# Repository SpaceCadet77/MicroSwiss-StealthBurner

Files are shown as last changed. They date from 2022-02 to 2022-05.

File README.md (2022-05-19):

# MicroSwiss-StealthBurner
Voron StealthBurner modified to work with a MicroSwiss Direct drive extruder system or Creality, Ender, CR-10 Printer.    

Thingiverse: https://www.thingiverse.com/thing:5232759
Printables: https://www.printables.com/model/157664-micro-swiss-stealthburner-beta

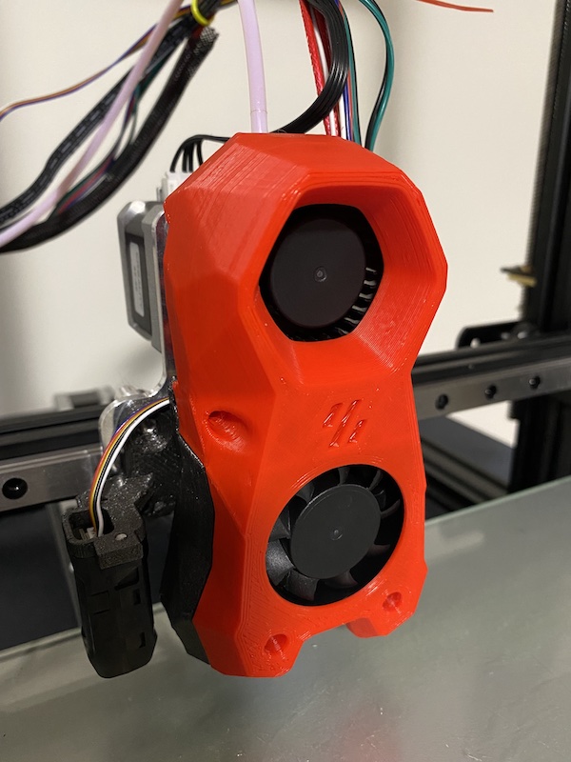
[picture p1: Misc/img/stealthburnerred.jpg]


## May 5, 2022:
- Fixed height adjustment
- Universal Mounting plate
- Use bottom insert for better adjustment
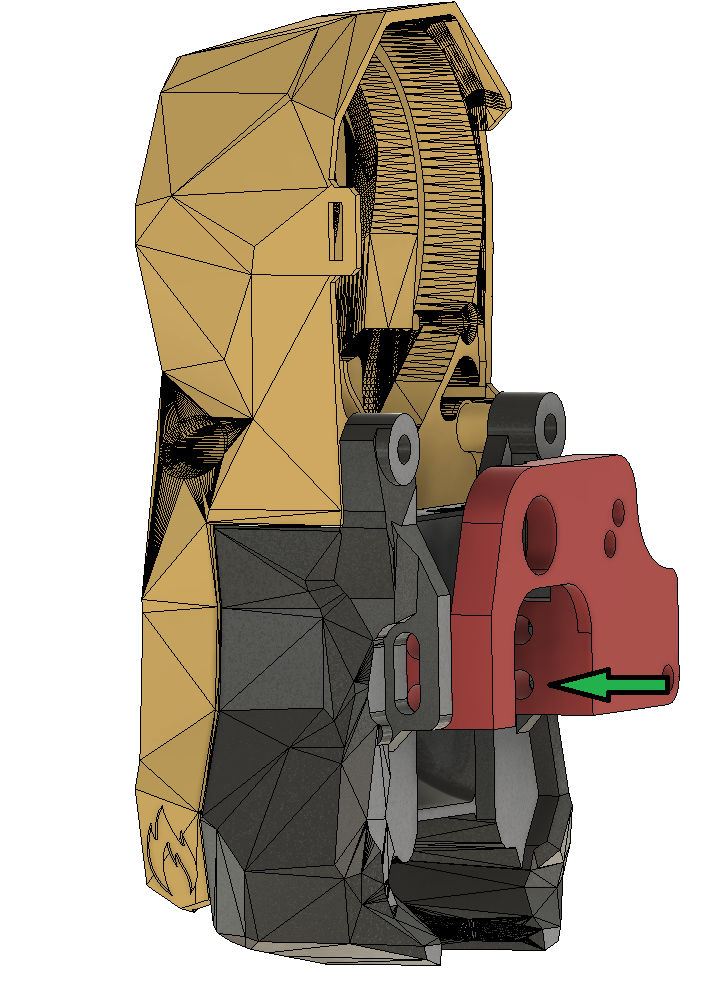
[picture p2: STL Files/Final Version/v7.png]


## Apr 18, 2022: 
- Was asked for an Ender3V2 Mounting plate. I took the dimensions from an existing STP file on Thingiverse (https://www.thingiverse.com/thing:4573240)
- If anyone is willing to test print/comment on changes
- Added through holes for wheel bolts
- Changed mouting bolt location
- File is Ender3V2PlateMountv1
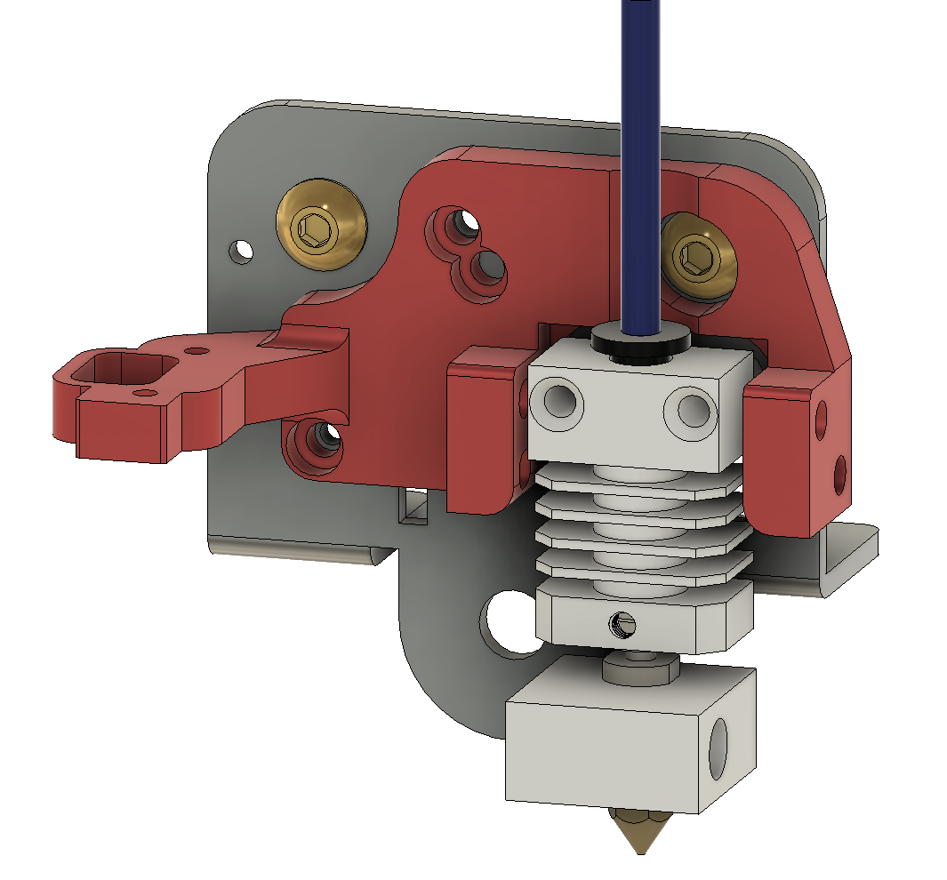
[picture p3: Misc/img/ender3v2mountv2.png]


## Mar 19, 2022: 
- Modified Fan_Sytem_V6, I have removed the bottom sections for Neopixels
- This is basically to clean it up if you arent using them, and to provide more room to view/work.
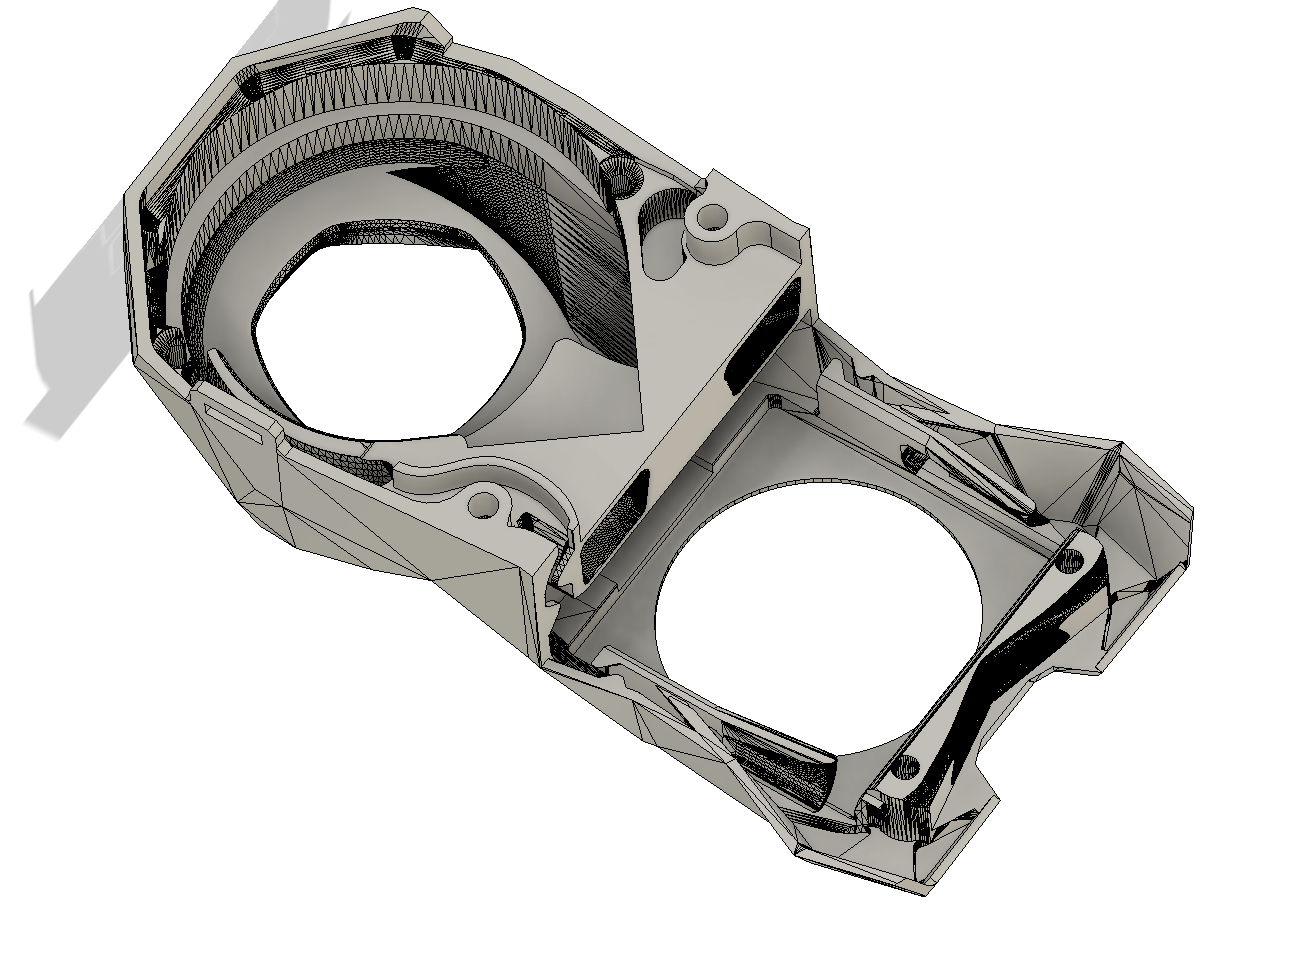
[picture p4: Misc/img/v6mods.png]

- Added some cable managment.

- Modified Duct_System_V6, by removing the inner splitter.
- I suppose I get the original intent, but at this scale creates backpressure.  
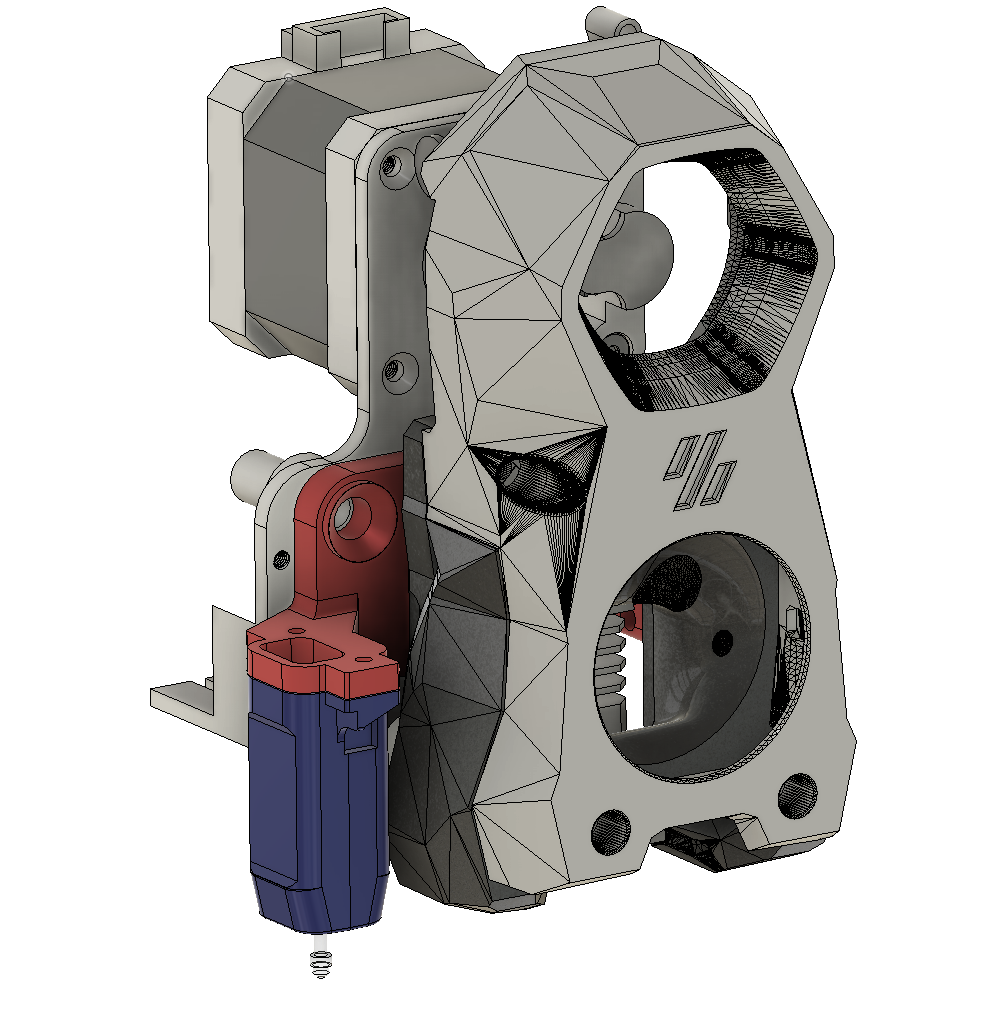
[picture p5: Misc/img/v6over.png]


- I have not printed these yet**
- 
## Feb 12, 2022: 
- Added vertical adjustment to Duct_System_V5.stl
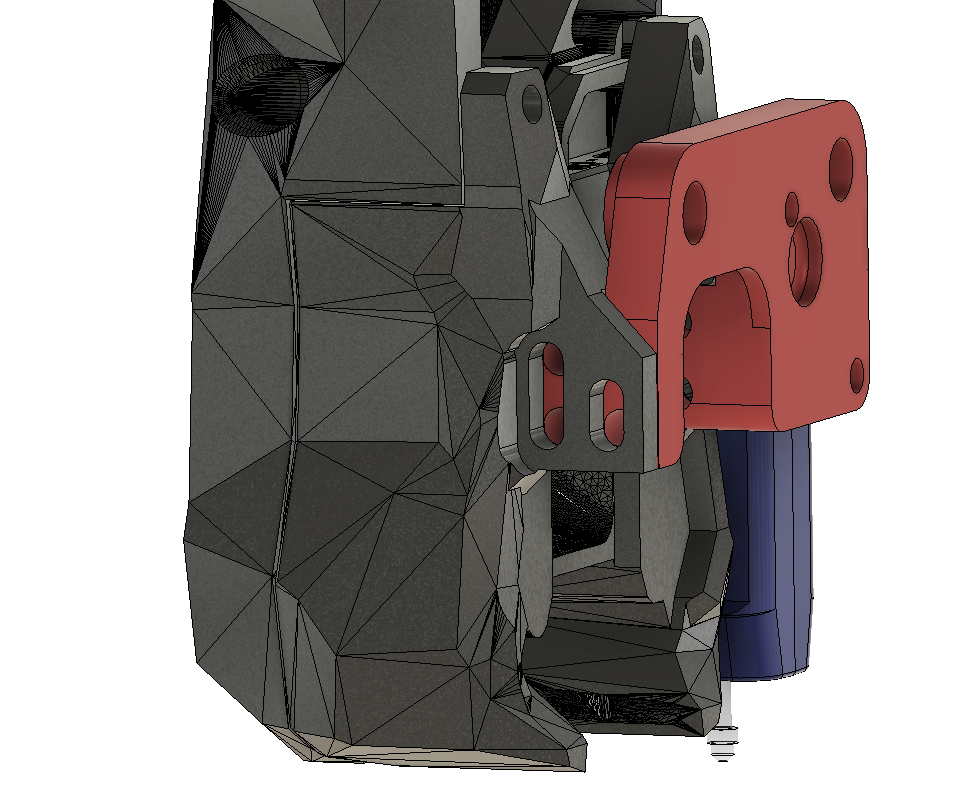
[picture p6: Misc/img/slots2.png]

- Added vertical adjustment holes to back_plate_mount_CRTouch_V5.stl.
- Will edit threaded instert depths, as there isnt much room for squishout 

## Feb 11, 2022: 
- Added Cable tie on right side (Fan_System_V5.stl)
- Added solid extrusion to remove the front logo through hole. This is used in the case you do not want to add an LED logo. (Fan_System_V5.stl)
- Added Extrusion Knob V1. Center Bore is 5.2 mm, OD is 47.0 mm, thickness is 5.0 mm
- Removed sectioned required for clockwork 2, unneeded for this mod. (Fan_System_V5.stl)

Files:
- back_plate_mount_CRTouch_V4.stl
- back_plate_mount_No_Probe_V4.stl
- Duct_System_V4.stl
- Fan_System_V5.stl

## Feb 4, 2022:
- This does not require any hardware modifications.
- This is still a beta design, as reverse engineering an STL is difficult.

Files:
- back_plate_mount_CRTouch_V4.stl
- back_plate_mount_No_Probe_V4.stl
- Duct_System_V4.stl
- Fan_System_V4.stl

Stay tuned for an additional modifications:

Extruder wheel (In Progress)
Extruder wheel side cutout of Fan System body (In Progress)
Wire management

Notes:
- The back plate and Duct System are currently attached with 4 M3*10 mm cap screws. This was to reduce a moment. After installation, it seams one screw on each side is sufficient.
- The Duct System and Back Mounting Plate are designed to use M3 threaded insert's (Red).
- There are 4 mounting locations (Green), I tapped the two wheel holes on the back mounting plate with a 1/4-20 tap. After mounting realized that's maybe a bit overkill, we'll see.

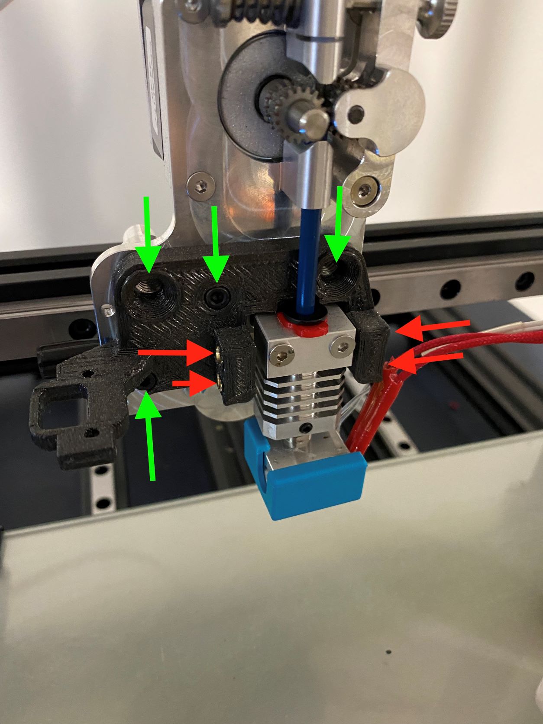
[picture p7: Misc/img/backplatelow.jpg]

     
- After calibrating my CR-Touch, my offset was -1.94, But please don't trust this value, as yours will be different. Probe to Nozzle was around 44, and 7 mm. This is mounted with 2 M3 screws, I did not use threaded inserts for this, but simply tapped the PETG.
- The Duct system currently requires supports for the top two "ears". I can probably redesign this with a 45 degree slope.

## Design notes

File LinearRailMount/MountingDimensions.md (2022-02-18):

To mount the Cr10/ender style microswiss backplate to the MGN12 linear block, I had to drill 3* 4mm holes.
This allowed a little bit of play for the M3*12mm screws. 
Using an ender5 style backplate would of been easier, but this has been working fine. 
Dimensions are shown below.

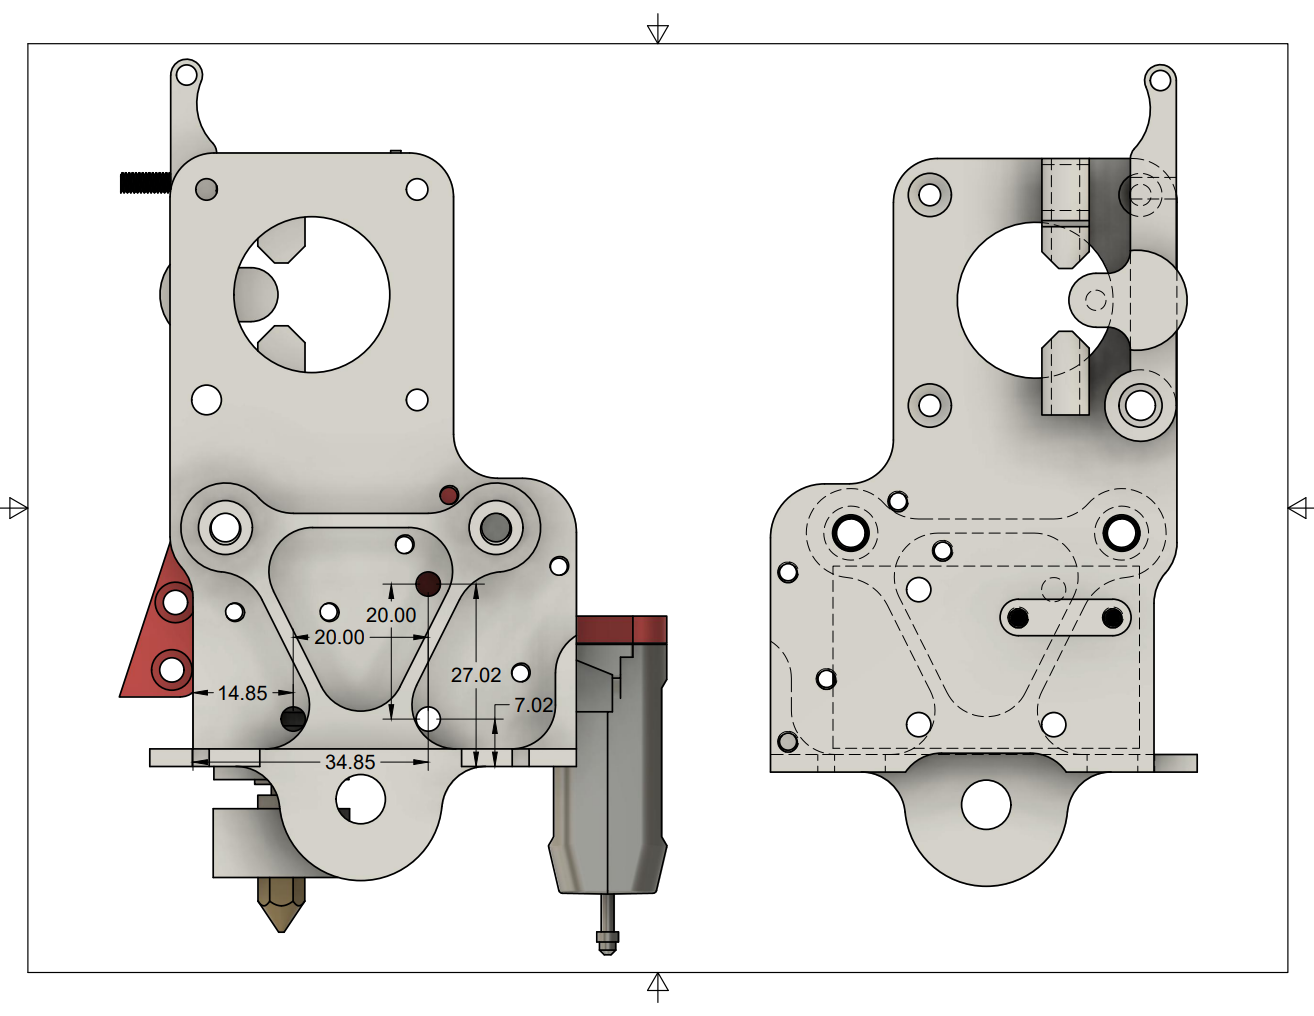
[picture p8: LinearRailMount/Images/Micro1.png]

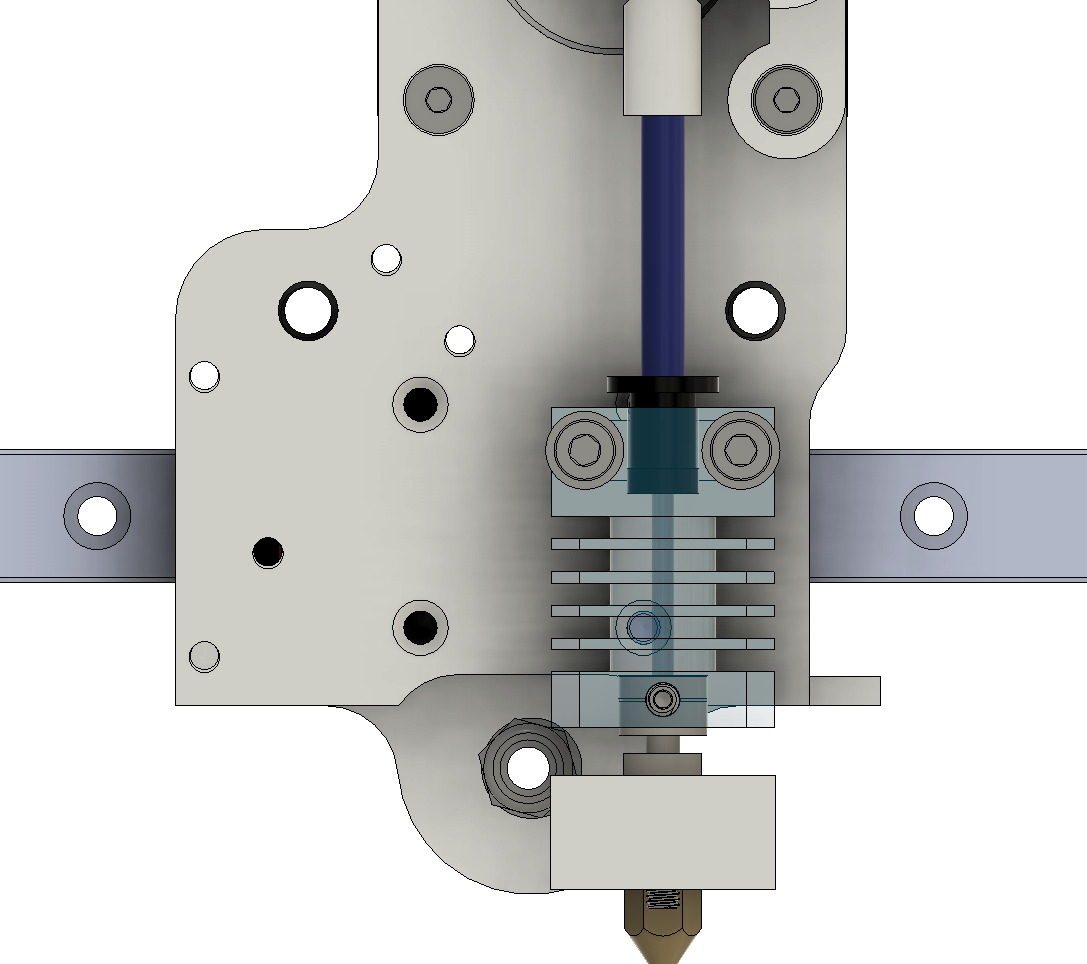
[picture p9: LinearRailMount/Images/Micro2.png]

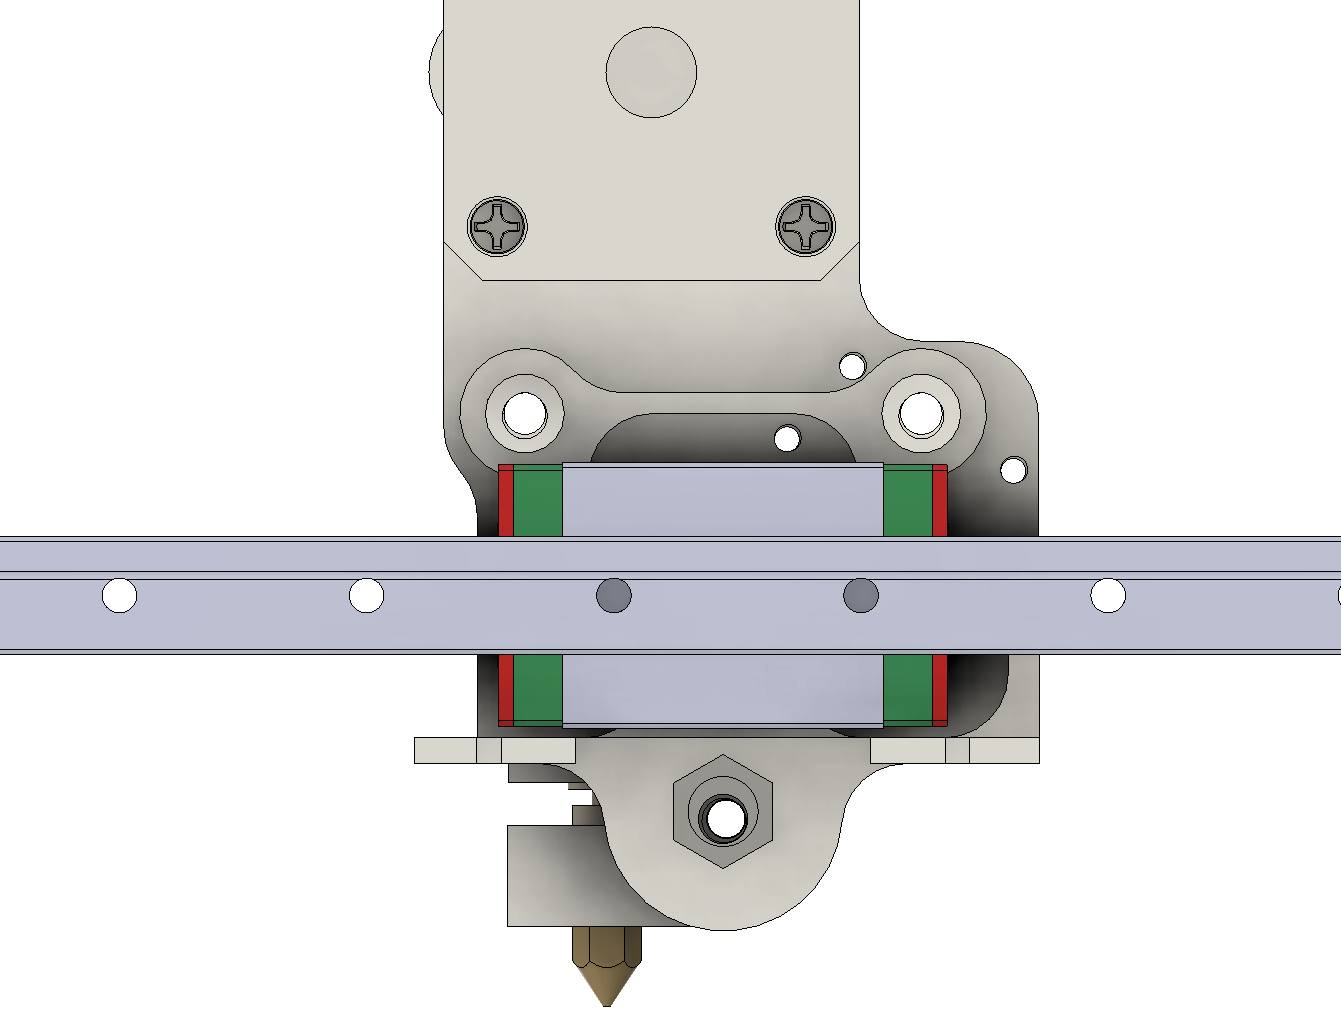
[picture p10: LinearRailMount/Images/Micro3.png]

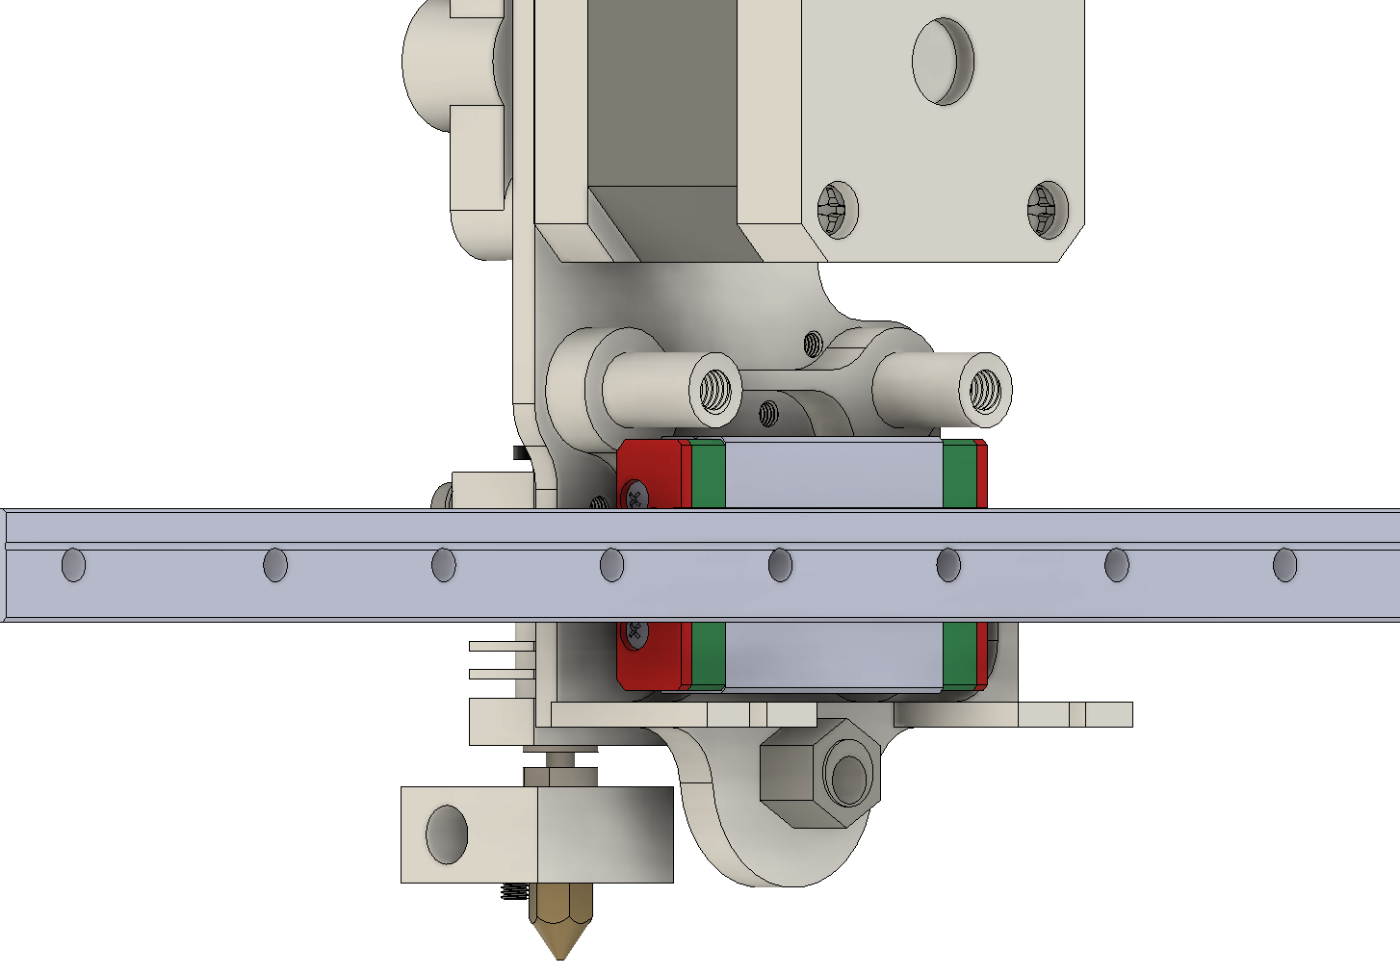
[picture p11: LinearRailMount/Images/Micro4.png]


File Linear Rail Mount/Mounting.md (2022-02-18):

To mount the original CR-10/Ender Style Microswiss plate to a MGN12 block, I drilled 3 holes in the microswiss Backplate. 
Dimensions are shown below. 




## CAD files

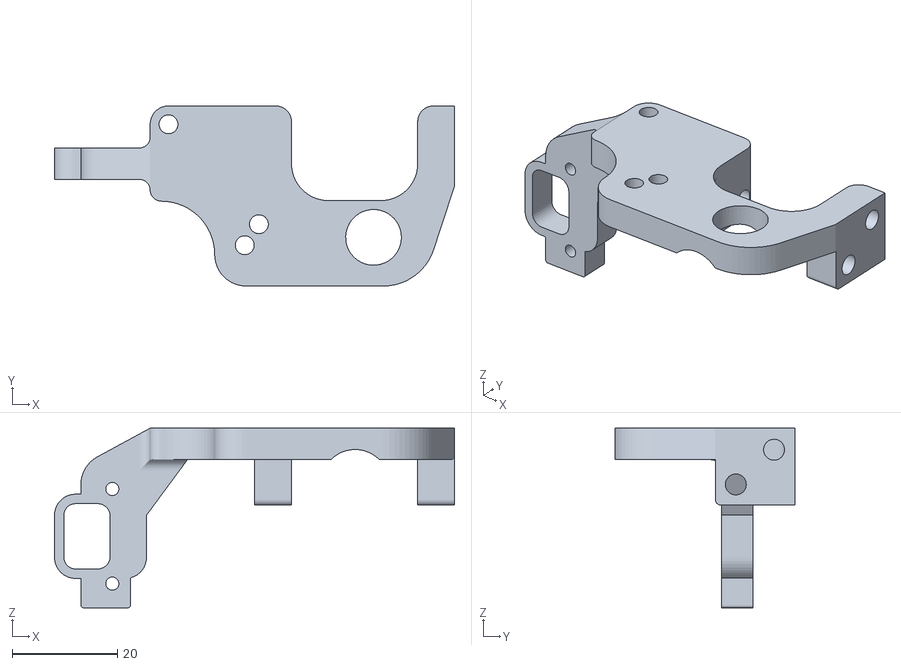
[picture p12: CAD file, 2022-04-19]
STL Files/Ender3V2PlateMountv1.stl
76.1 x 34.3 x 34.2

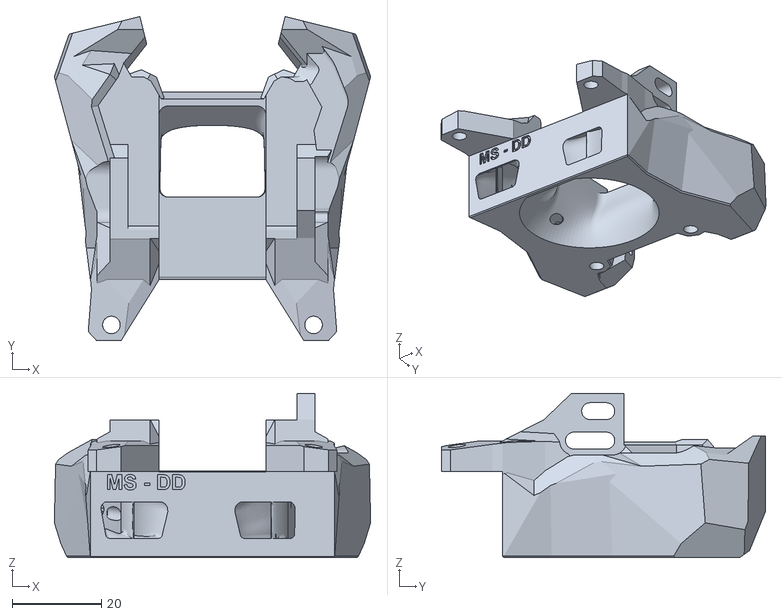
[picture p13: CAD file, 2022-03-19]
STL Files/Duct_System_V6.stl
71.1 x 72.8 x 36.9

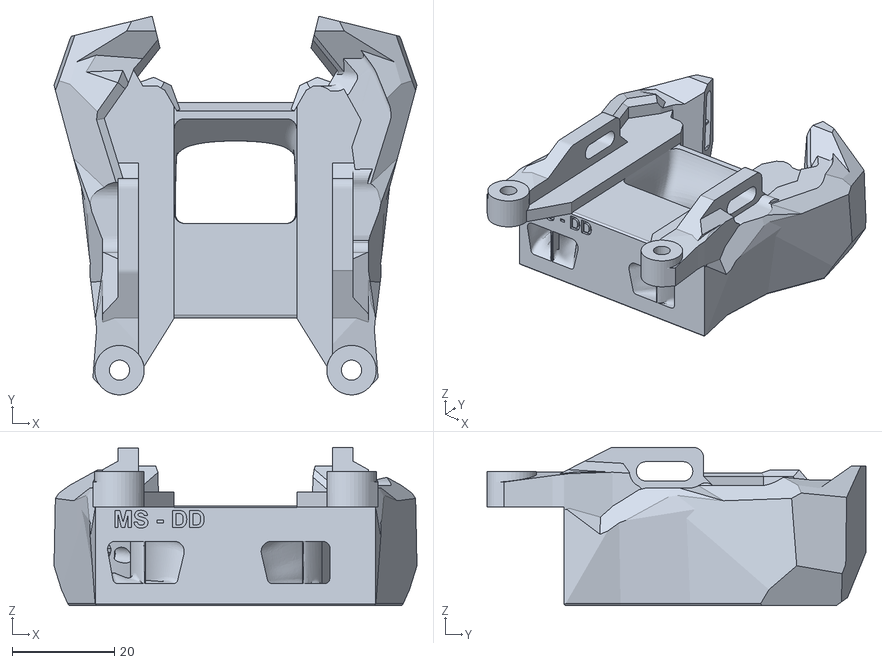
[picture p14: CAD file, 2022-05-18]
STL Files/Final Version/Duct_V7.stl
71.1 x 74.1 x 31.0

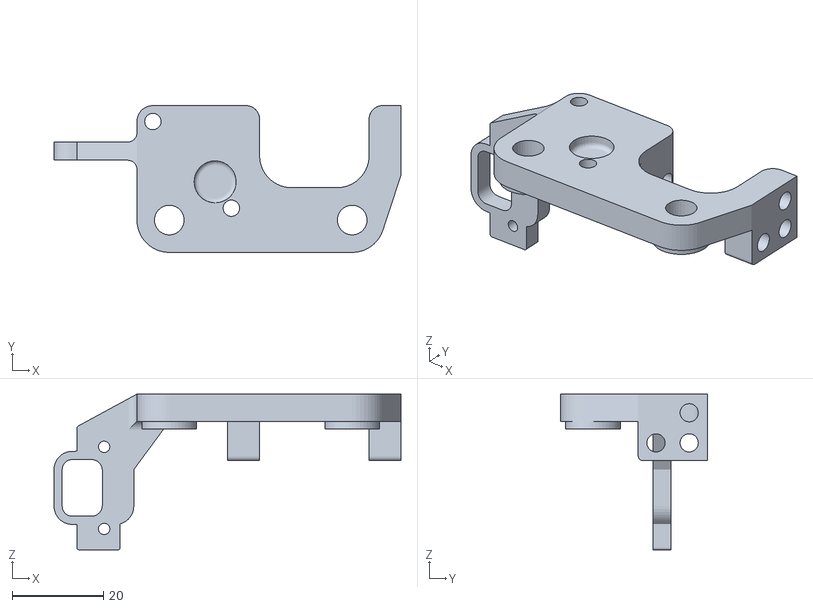
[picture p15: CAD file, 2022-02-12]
STL Files/back_plate_mount_CRTouch_V5.stl
76.1 x 32.2 x 34.2

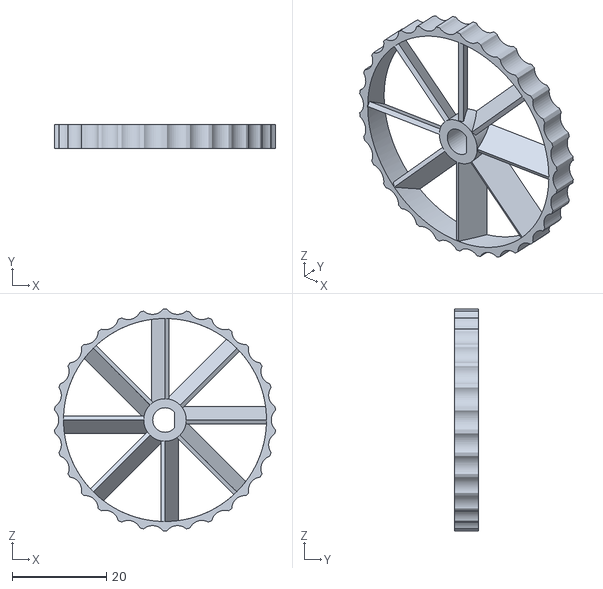
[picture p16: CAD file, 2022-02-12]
STL Files/Extruder Knob V1.stl
46.8 x 5.00 x 47.0

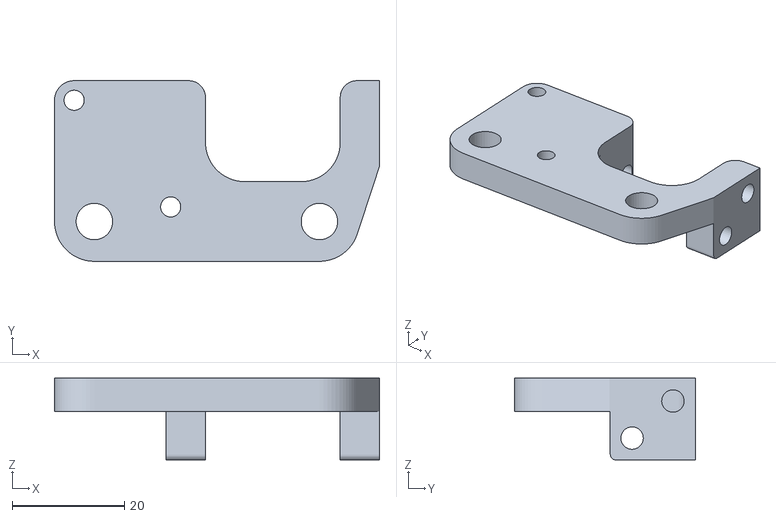
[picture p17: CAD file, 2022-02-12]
STL Files/back_plate_mount_No_Probe_V4.stl
57.9 x 32.2 x 14.6

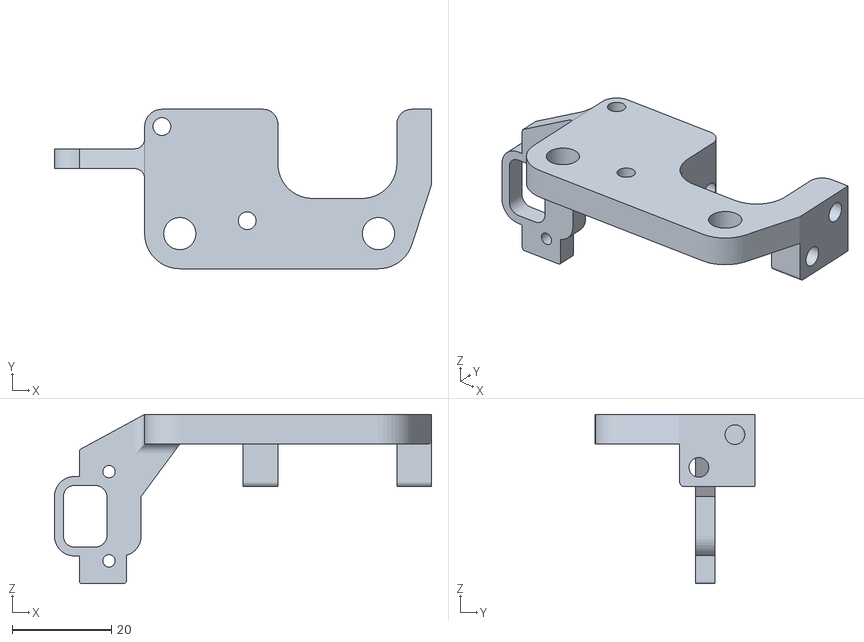
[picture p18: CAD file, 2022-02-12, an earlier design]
STL Files/back_plate_mount_CRTouch_V4.stl
76.1 x 32.2 x 34.2

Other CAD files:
STL Files/Final Version/Ender3V2PlateMount_V7.stl

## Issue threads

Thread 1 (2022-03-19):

4020 fan

Nelus82, 2022-03-19:
Is it possible to create room for a 4020 fan?

SpaceCadet77, 2022-04-19:
I saw someone made a remix, maybe you? https://www.printables.com/model/162228-micro-swiss-stealthburner-stealthyswiss-for-the-ex

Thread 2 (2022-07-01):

BLTouch Mount

CTJohnson, 2022-07-01:
Hello,

First, great work!

I'd like to kindly request a BLTouch mount, please.

I have a CR-10 Max which doesn't have the CRTouch, so I am trying to adapt and its a bit cumbersome. I've made it work with putting inserts into the CRTouch mounting holes.

Thanks and Kind Regards

Chris

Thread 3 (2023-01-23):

Linear rail adapter plate?

W141-ID, 2023-01-23:
First of all huge thanks for this amazing mod. It's exactly what I have been thinking about.

Maybe a future addition:
Instead of drilling into the aluminum plate, one could model an adapter plate and make it compatibel to the corexz mod at the same time.
If I find the time I would be willing to work on that.

Closed 2023-05-25.

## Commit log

2022-02-12 Create STL Files
2022-02-12 STL Files
    [back_plate_mount_CRTouch_V4.stl, back_plate_mount_No_Probe_V4.stl]
2022-02-12 Create Current Files
2022-02-12 Add files via upload
    Fixed Cable Clip
2022-02-18 Update and rename Mounting.md to MountingDimensions.md
